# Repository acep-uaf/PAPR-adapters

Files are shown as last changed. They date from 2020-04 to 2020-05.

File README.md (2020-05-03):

# PAPR-adapters

Positive Air Pressure Respirator (PAPR) devices pull air through a filter and push it into a mask over the user's head.  This produces much better protection against droplets than N95 masks or face shields.

A full PAPR system consists of multiple parts:
 * PAPR unit: battery, controller & sensors, air filter, and hose
 * PAPR hose: hose with an end port to connect to a hood
 * PAPR hoods with a hood port

PAPR systems are built to work with a set of components from a specific vendor model and is enforced through physical connector incompatibility between components like hood and hose. Different manufactures hoods and PAPRs units will not work together and even the same manufacture and different models are sometimes incompatible.

The PAPR-adapter project's goal is to provide adapters between different PAPR components to allow them to work together. This allows groups with multiple PAPR units and older/alternative PAPR hoods in their inventory the option of using hoods from one vendor on another vendor's PAPR. This is not typically allowed or considered best practice however in the context of COVID-19 the increased access to limited supply of in-hand PPE is more important.

> USE AT YOUR OWN RISK - THIS IS A STOP-GAP SOLUTION

The PAPR adapter project has helped solve the following adaption problems:

- **Bullard Mask to 3M Hose**:
  2008 era Bullard Hoods to 3M Versaflo PAPR hose

- **Bullard Hose replacement**: 
  Hose connector replacement for older Bullard PAPR units due to breakage of the connector.

- **3M Older BE Hood to Newer 3M Versaflo Hose**: 
  Adapt older BE-10 or BE-12 snap-in hood to newer BT-20, BT-30, or BT-40 type clip-on hose.

- **3M Hood port** - _coming soon_
- **Bullard hood port** - _coming soon_

# Bullard Mask to 3M Hose
This adapts the round 3M PAPR hose to the bayonet-style socket on the Bullard mask/hood.  It allows Bullard Masks to be used with 3M PAPR units.

Mask side: Bullard PAPR hood - port adapter style like Bullard PA30 units.

Hose side: 3M Versaflo PAPR hose
  3M part numbers: BT-20, BT-30, or BT-40 like used in 3M Versaflo TR-6710N.

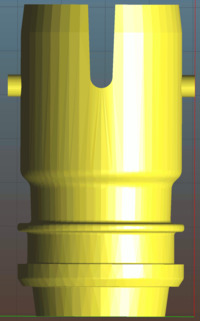
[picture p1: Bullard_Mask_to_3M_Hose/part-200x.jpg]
Top: bayonet-style Bullard mask connector. Bottom: 3M hose connector.


# Bullard Hose Replacement
This connects the corrugated Bullard PAPR hose to the bayonet-style socket on the Bullard mask/hood.  It's a 3D printable replacement for the factory Bullard PAPR hose end.

Mask side: Bullard PAPR hood

Hose side: Bullard PAPR hose

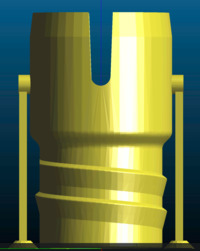
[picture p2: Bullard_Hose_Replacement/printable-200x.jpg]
Top: bayonet-style Bullard mask connector. Bottom: corrugated Bullard hose connector.


# 3M "BE Type" Mask to 3M Clip-On Hose
This plugs into:

Mask side: Older 3M BE-12 or BE-10 snap-in type mask (normally used with unique 3M BE-224 hose).

Hose side: Newer 3M BT-20, BT-30, or BT-40 clip-on type hose.

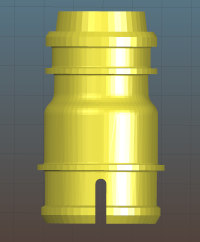
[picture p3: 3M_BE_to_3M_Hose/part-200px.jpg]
Top: 3M clip-on type hose connector. Bottom: 3M snap-in mask connector.


# Sanitization and Safe Use
These parts were designed during the 2020 national COVID-19 crisis as emergency replacement parts to get PAPR units into service.  If you fabricate these parts, they MUST to be checked for material, strength, and dimensional compatibility with the PAPR machines used.  

3D printing can leave crevices that may not be reached by a wipe down, and almost no ordinary plastics can survive an autoclave, so we recommend full immersion sanitization.  NIH 2014 "Infection Prevention and Control of Epidemic- and Pandemic-Prone Acute Respiratory Infections in Health Care" Annex G lists ethanol at 70%, or bleach at 0.05% hypochlorite / 500ppm available chlorine (100 parts cold tap water to 1 part household 5% bleach) for at least 30 minutes.  The bleach solution will need to be rinsed off with water afterwards, or it will leave salt spots.

The UAF Engineering machine shop has tooling to create a strong smooth machined Delrin version of the Bullard Mask to 3M Hose adapter.  Contact uaf-oipc@alaska.edu for pricing and availability.

3M Versaflo and Bullard are trademarks of their respective companies.  These files were developed with support from the University of Alaska Fairbanks Center for Intellectual Property, Commercialization, and Entrepreneurship, including funding from the Office of Naval Research.

# Credits

The PAPR adapters were put together by a team of researchers and engineers at the University of Alaska Fairbanks with funding support from the Office of Naval Research.

* Benjamin Loeffler <bhloeffler@alaska.edu> - Model designer
* Orion Lawlor <oslawlor@alaska.edu> - 3d Printing lead
* Eric Johansen <lejohansen@alaska.edu> - CNC coding for durable/reusable parts
* Dayne Broderson <dbbroderson@alaska.edu> - User interfacing and design requirements
* Greg Shipman <gkshipman@alaska.edu> - 3D printing & consulting

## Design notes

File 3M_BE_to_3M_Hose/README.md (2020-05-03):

# 3M "BE Type" Mask to 3M Clip-On Hose
This plugs into:

3M BE-12 or BE-10 snap-in type mask, normally used with a 3M BE-224 hose.

3M BT-20, BT-30, or BT-40 clip-on type hose.

Top: 3M clip-on type hose connector. Bottom: 3M snap-in mask connector.

The SLDPRT SolidWorks original was designed by Benjamin Loeffler <bhloeffler@alaska.edu>.

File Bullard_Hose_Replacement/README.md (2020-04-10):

# Bullard Hose Replacement
This is a 3D printed replacement for factory Bullard PAPR hose to mask connection.

You use heat shrink tubing to connect the hose to this adapter.

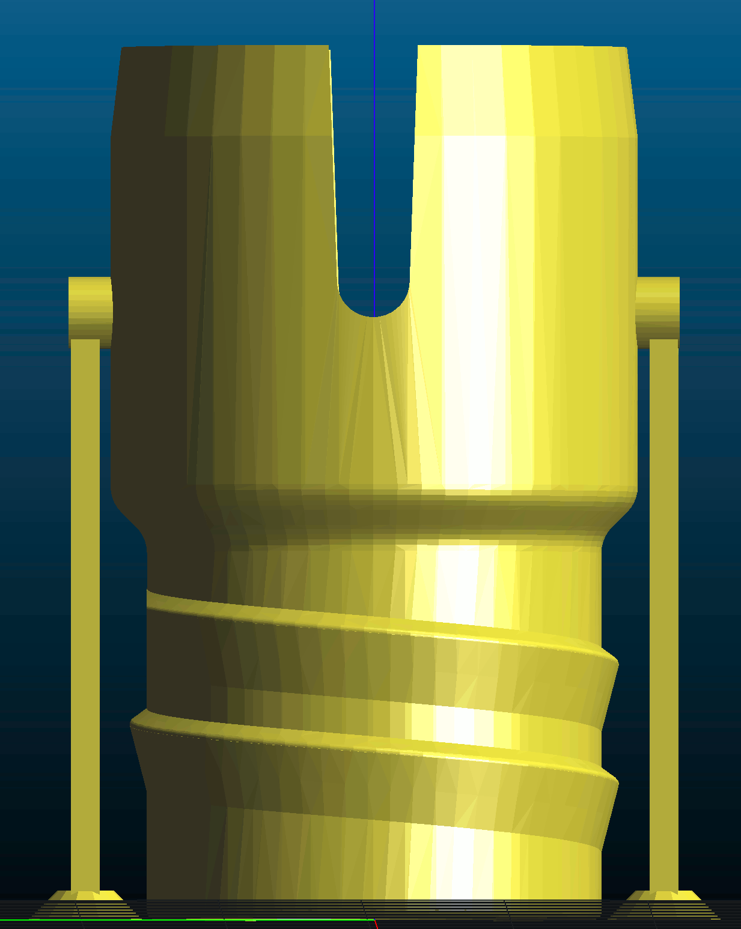
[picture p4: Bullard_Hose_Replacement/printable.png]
Top: bayonet-style Bullard mask connector. Bottom: corrugated Bullard hose connector.


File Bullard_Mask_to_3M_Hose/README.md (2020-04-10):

# Bullard Mask to 3M Hose
This plugs into the round 3M PAPR-side hose, and lets it connect to the bayonet-style Bullard mask/hood.

It allows you to use a Bullard mask/hood with a 3M Versaflow PAPR unit.

Because the round features on the 3M side are rather challenging to 3D print effectively, the "lathe_finished" directory includes extra material that is machined away.

The SLDPRT SolidWorks original was designed by Benjamin Loeffler <bhloeffler@alaska.edu>.  The CNC and 3D printing adaptations were designed by Dr. Orion Lawlor <lawlor@alaska.edu>.

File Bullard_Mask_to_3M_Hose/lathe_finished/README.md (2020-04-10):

# Lathe Finished Version

This version includes extra 3D printed material on the 3M side, 
which is then machined off on a CNC lathe using the gcode in cleanup_operation_lathe.ngc.

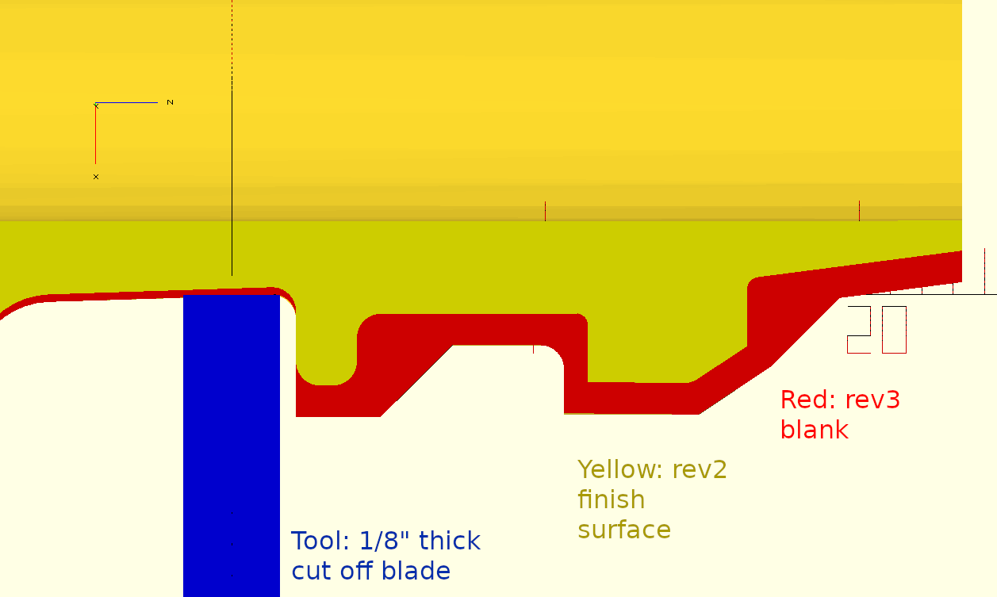
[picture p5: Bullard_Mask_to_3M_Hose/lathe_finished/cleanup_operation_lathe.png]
Gcode for the lathe cleanup operation


The "_upright" version is designed to be 3D printed directly on the print
bed without additional support material--it has two tiny diagonal supports
around the Bullard "ears".

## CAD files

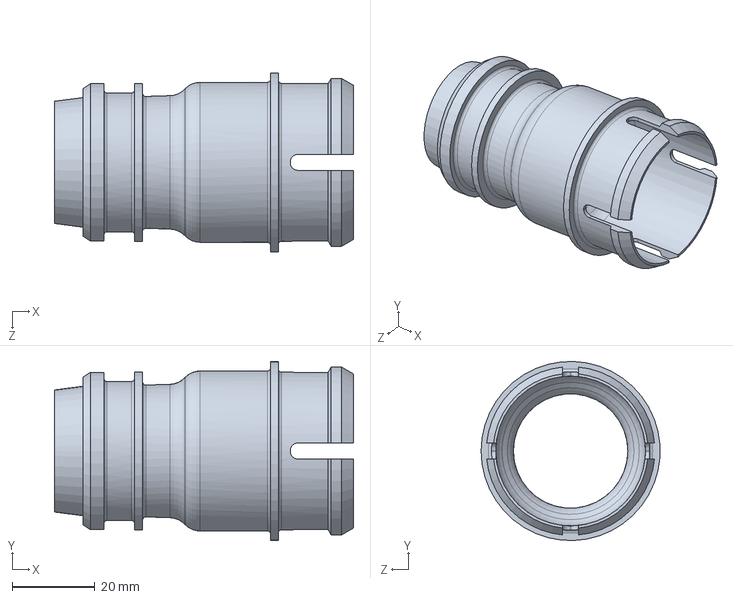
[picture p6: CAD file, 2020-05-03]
3M_BE_to_3M_Hose/BE_3M_adapter_rev2_thin.SLDPRT
72.1 x 43.2 x 43.1 mm

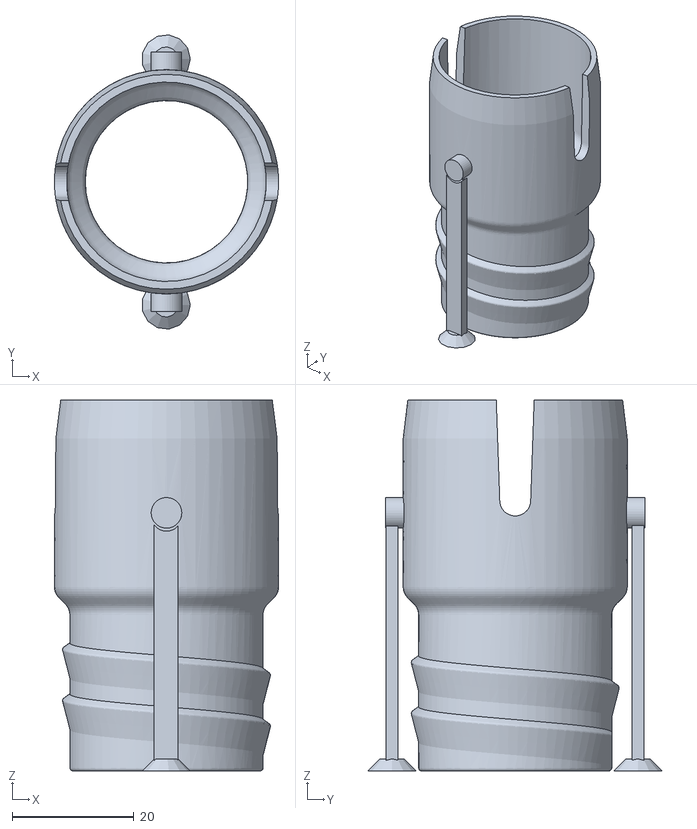
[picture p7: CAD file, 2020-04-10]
Bullard_Hose_Replacement/printable_Bullard_Hose_Replacement_rev2.stl
36.8 x 48.3 x 61.0

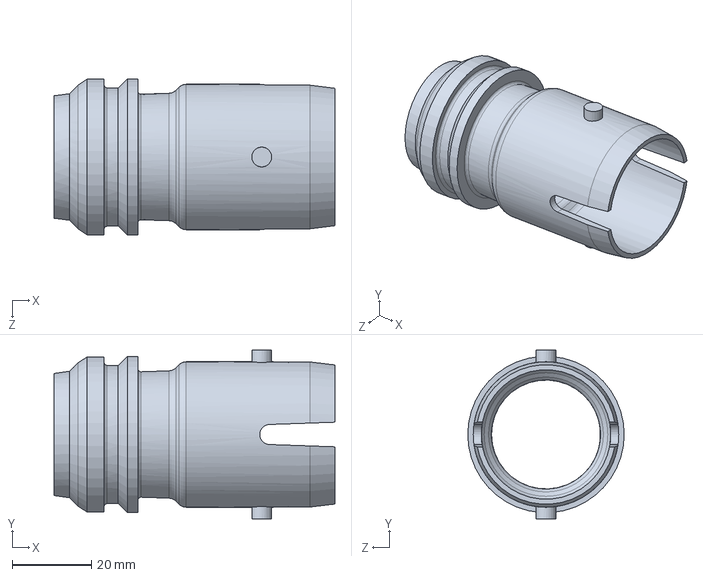
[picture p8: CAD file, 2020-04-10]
Bullard_Mask_to_3M_Hose/lathe_finished/Bullard_Mask_to_3M_Hose_rev3_ForLathe.SLDPRT
71.1 x 42.7 x 39.6 mm

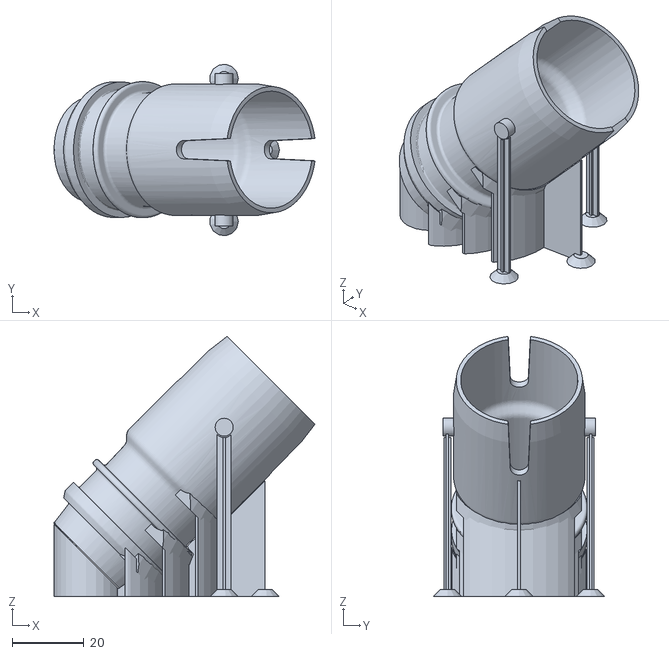
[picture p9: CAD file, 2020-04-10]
Bullard_Mask_to_3M_Hose/printable_Bullard_Mask_to_3M_Hose.stl
73.0 x 47.9 x 72.8

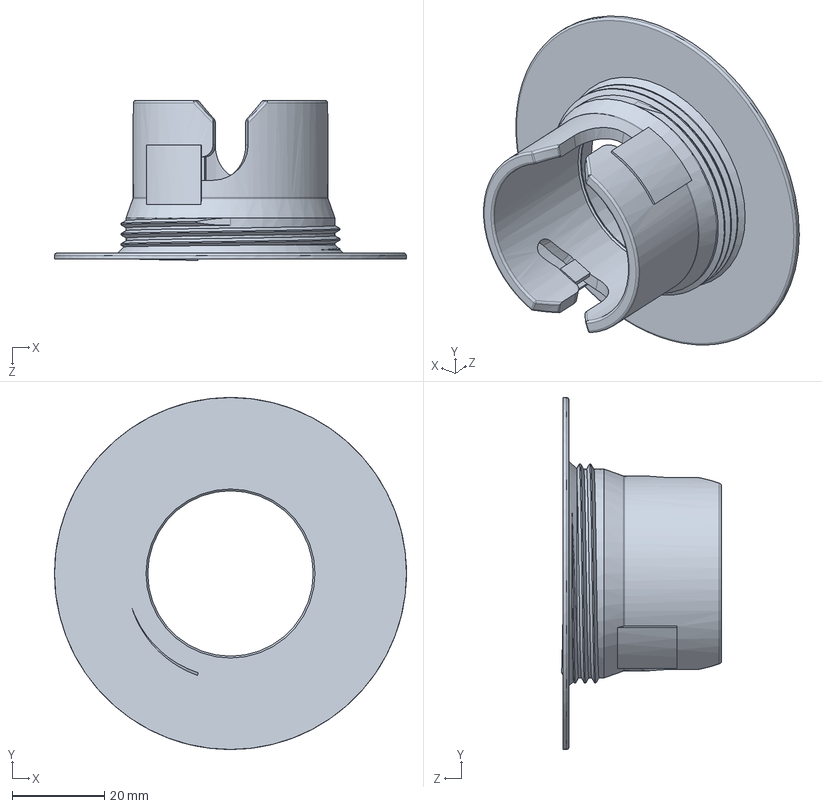
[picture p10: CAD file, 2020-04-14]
Bullard_Socket/Bullard_Socket_threaded_rev2.SLDPRT
76.2 x 76.2 x 34.6 mm

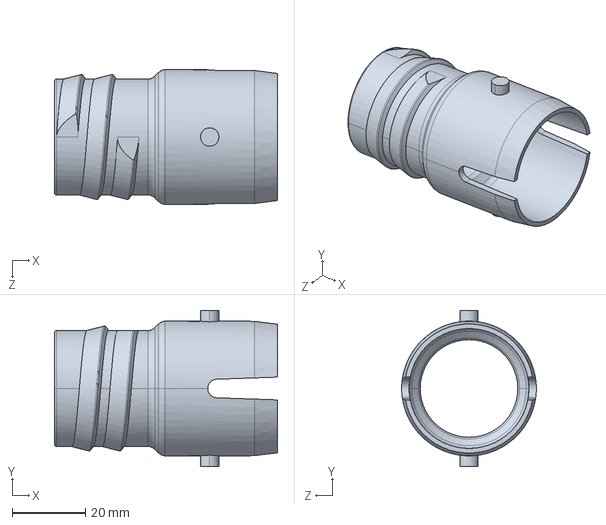
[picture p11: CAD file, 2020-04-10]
Bullard_Hose_Replacement/Bullard_Hose_Replacement_rev2.STEP
61.0 x 42.7 x 36.8 mm

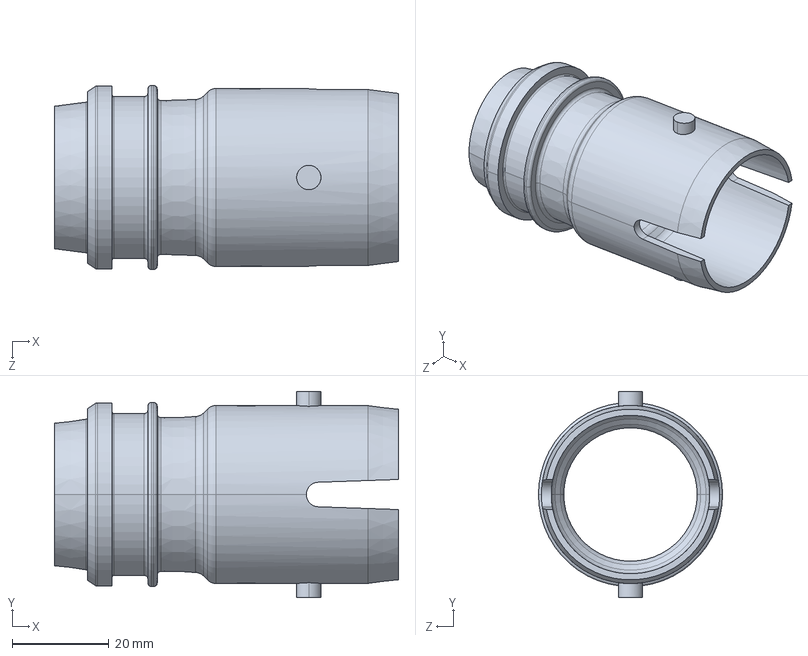
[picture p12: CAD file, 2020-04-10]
Bullard_Mask_to_3M_Hose/Bullard_Mask_to_3M_Hose.STEP
71.1 x 42.7 x 38.1 mm

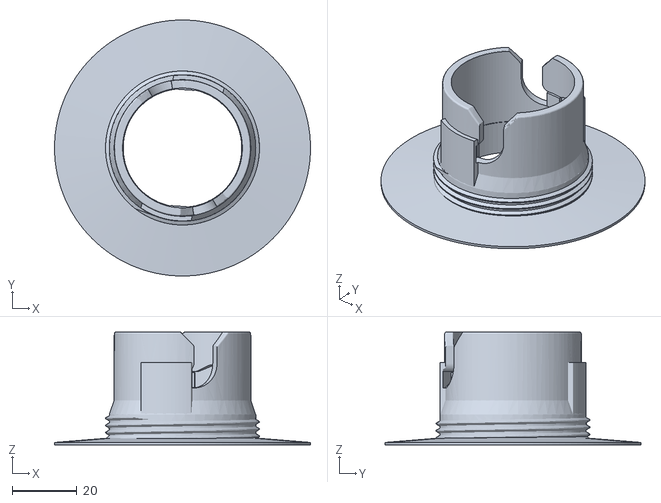
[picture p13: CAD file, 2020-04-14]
Bullard_Socket/Bullard_Socket_v3.stl
79.0 x 79.0 x 34.9

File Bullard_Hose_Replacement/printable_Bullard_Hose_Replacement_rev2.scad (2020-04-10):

/*
  Support material for Bullard Hose Replacement, standing upright.
  
  OpenSCAD code by Dr. Orion Lawlor, 2020-04-03
*/

spacing=0.5;

module main_part()
{
	translate([18.5,-21.3])
	rotate([0,-90,0])
		import("Bullard_Hose_Replacement_rev2.stl");
}

module support_material() 
{
	height=42;
	for (side=[-1,+1]) scale([1,side,1])
		translate([0,20.2,0])
		union() {
			translate([0,0,height/2])
				cube([4,2,height],center=true);
			
			cylinder(d1=8,d2=4,h=2);
		}
}

main_part();
difference() {
	support_material();
	
	// Leave space around the main part
	translate([0,0,-spacing])
		main_part();
}

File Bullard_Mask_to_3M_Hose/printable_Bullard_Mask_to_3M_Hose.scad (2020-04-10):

/*
  Support material for Bullard_Mask_to_3M_Hose,
  tilted over sideways, and supported.
  
  OpenSCAD by Dr. Orion Lawlor <lawlor@alaska.edu>
*/

spacing=0.4; // distance between support material and part
height=53; // original upright distance to pegs
tiltover=45; // angle of tilt (0==upright)
support_height=47.5; // post-rotate distance to pegs
support_width=0.7;

// Comes out upright and centered
module main_part()
{
	translate([18.8,-21.25])
	rotate([0,-90,0])
		import("Bullard_Mask_to_3M_Hose.stl",convexity=6);
}

// Main part, with inside filled in solid (to cut support material)
module main_part_solid() {
	main_part();
	cylinder(d=28,h=45);
	translate([0,0,43]) cylinder(d=34,h=30);
}

// Tilt part over to printable orientation
module part_tilt() {
	translate([0,0,+support_height])
	rotate([0,tiltover,0])
	translate([0,0,-height])
		children();
}

// Tapered stick down
module stickdown() {
	cylinder(d1=8,d2=4,h=2);
}


// Support-type rings are defined relative to un-tilted part
module support_ring(z,OD,wall,topclip,flare=1)
{
	color([1,0,0]) union() {
		difference() {
			// Project down to support each ridgeline
			linear_extrude(height=30,convexity=4)
			projection(cut=false)
			part_tilt()
			translate([0,0,z])
			{
				linear_extrude(height=1)
				difference() {
					circle(d=OD);
					circle(d=OD-2*wall);
					translate([topclip-100,0,0]) square([200,200],center=true);
				}
			}
		
			// Trim those supports along (tilted) z
			part_tilt()
			translate([0,0,z+1+100])
				cube([200,200,200],center=true);
		}
		
		if (flare) { // flare out object contact surface
			part_tilt() {
				intersection() {
				translate([0,0,z-1.5]) {
					cylinder(d1=OD+3,d2=OD-1,h=4.5);
					/*
					scale([1,1,-1])
					cylinder(d1=OD+5,d2=OD-2,h=1);
					*/
				}
				translate([OD/2,0,z])
					cube([30,35,100],center=true);
				}
			}
		}
	}
}

// Support towers over pegs
module support_towers()
{
	for (side=[-1,+1]) scale([1,side,1])
		translate([-0.5,20.0,0])
		union() {
			translate([0,0,support_height/2]) union() {
				cube([4,support_width,support_height],center=true);
				cube([support_width,2,support_height],center=true);
			}
			
			stickdown();
		}
}

module all_support_material() {
	difference() {
		union() {
			spine_length=38;
			spine_width=support_width;
			translate([-27,0,0]) 
			{
				difference() {
					translate([0,-spine_width/2,0])
					cube([spine_length,spine_width,50]);
					translate([0,0,0.5]) rotate([0,-90+tiltover+2,0]) 
						translate([0,0,100]) cube([200,200,200],center=true);
				}
				
				// Support the part base
				translate([-1.5,0,2]) cube([5,20,4],center=true);
				
				// Keep tip from coming up
				translate([spine_length,0,0])
					stickdown();
			}
			
			ring_width=support_width*0.5;
			support_ring(-0.8,28.2,ring_width,-50,0);
			support_ring(8.2,39,ring_width,5);
			support_ring(18.0,39,ring_width,10);
			support_ring(31,37,ring_width,10);
			
			support_towers();
		}
		
		// Leave space around the main part
		for (shift=[[0,0,-spacing],[0,+spacing,0],[0,-spacing,0],[spacing,0,0],[0,0,+spacing]])
			translate(shift)
				part_tilt() main_part_solid();
	}
}

intersection() {
	union() {
		part_tilt() main_part();

		all_support_material();
	}
	
	// Trim bottom flat
	color([0,1,0])
	translate([0,0,100]) cube([200,200,200],center=true);
}

if (0) difference() {
	main_part_solid();
	cube([100,100,100]);
}

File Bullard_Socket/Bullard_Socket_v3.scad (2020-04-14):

/*
 Female socket for Bullard Hoods.
*/

$fs=0.1;
$fa=3;
inch=25.4; // file units are mm

ID=1.455*inch;// male side fits in here
OD=41.0; // OD of main outside
OD_track=43.5; // OD along bottom of peg track
TD=OD+2*2;

bottom_shorten=4.5;
new_bottom=TD+17*2;

module fit_test_male() {
	translate([0,0,72.7])
	scale([1,1,-1])
		import("../PAPR_adapter/Old_Mask_to_New_Hose_rev3_upright.stl",convexity=4);
}

module connector() {
	rotate([0,0,20])
	translate([-76.2/2,76.2/2,39.37])
	rotate([180,0,0])
	import("Bullard Hood Connector_threaded.STL",convexity=8);
}

module thread_split(offset=0) {
	translate([0,0,-100+14.1+offset])
		cube([200,200,200],center=true);
}

module reinforced_connector() {
	// Outer lug supports (permanent)
	intersection() {
		rotate([0,0,-14])
		cube([16,100,100],center=true);
		difference() {
			translate([0,0,10])
				cylinder(d=TD,h=20);
			
			// Thru hole in middle
			translate([0,0,-1])
			cylinder(d=OD,h=32);
			
			// Extra-deep tracks
			difference() {
				translate([0,0,20])
				cylinder(d=OD_track,h=12);
			
				intersection() {
					s=OD_track/OD;
					translate([0,0,0.01])
					scale([s,s,1])
						connector();
					
					translate([0,0,25])
					cube([30,100,10],center=true);
				}
			}

		}
	}
	
	// Inner lug start support (temporary, removed after printing)
	rotate([0,0,-4]) {
		for (side=[-1,+1]) scale([1,side,1])
			translate([0,ID/2,24.6])
				cube([5,1,4.6],center=true);
	}
	
	
	difference() {
		union() {
			scale([-1,1,1]) 
			intersection() {
				connector();
				thread_split();
			}
			difference() {
				connector();
				thread_split(-0.01);
			}
		}
		
		// Clearance inside for male plug
		translate([0,0,15])
			cylinder(d=ID,h=100);
	}
}

module shortened_connector() {
	difference() {
		translate([0,0,-bottom_shorten])
			reinforced_connector();

		// Cut off bottom flush
		translate([0,0,-100+0.001])
			cube([200,200,200],center=true);
		
	}
	
	difference() {
		union() {
			cylinder(d=new_bottom,h=0.7);
			translate([0,0,0.8-0.01])
				cylinder(d1=new_bottom,d2=42,h=1.5);
			
			translate([0,0,0.1])
				cylinder(d1=OD+2*5,d2=OD,h=5);
		}
		cylinder(d=OD,h=100,center=true);
	}
}

difference() {
	union() {
		shortened_connector();
		// fit_test_male();
	}
	// cube([100,100,100]); // cutaway
}

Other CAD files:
Bullard_Mask_to_3M_Hose/lathe_finished/printable_Bullard_Mask_to_3M_Hose_rev3.stl
Bullard_Mask_to_3M_Hose/lathe_finished/printable_Bullard_Mask_to_3M_Hose_rev3.scad
3M_BE_to_3M_Hose/BE_3M_adapter_rev2_thin.stl
Bullard_Hose_Replacement/Bullard_Hose_Replacement_rev2.SLDDRW
Bullard_Hose_Replacement/Bullard_Hose_Replacement_rev2.SLDPRT
Bullard_Hose_Replacement/Bullard_Hose_Replacement_rev2.stl
Bullard_Mask_to_3M_Hose/Bullard_Mask_to_3M_Hose.SLDDRW
Bullard_Mask_to_3M_Hose/Bullard_Mask_to_3M_Hose.SLDPRT
Bullard_Mask_to_3M_Hose/Bullard_Mask_to_3M_Hose.stl
Bullard_Mask_to_3M_Hose/lathe_finished/Bullard_Mask_to_3M_Hose_rev3_ForLathe.stl
Bullard_Mask_to_3M_Hose/lathe_finished/Bullard_Mask_to_3M_Hose_rev3_ForLathe.x_t
Bullard_Socket/Bullard_Socket_threaded_rev2.stl

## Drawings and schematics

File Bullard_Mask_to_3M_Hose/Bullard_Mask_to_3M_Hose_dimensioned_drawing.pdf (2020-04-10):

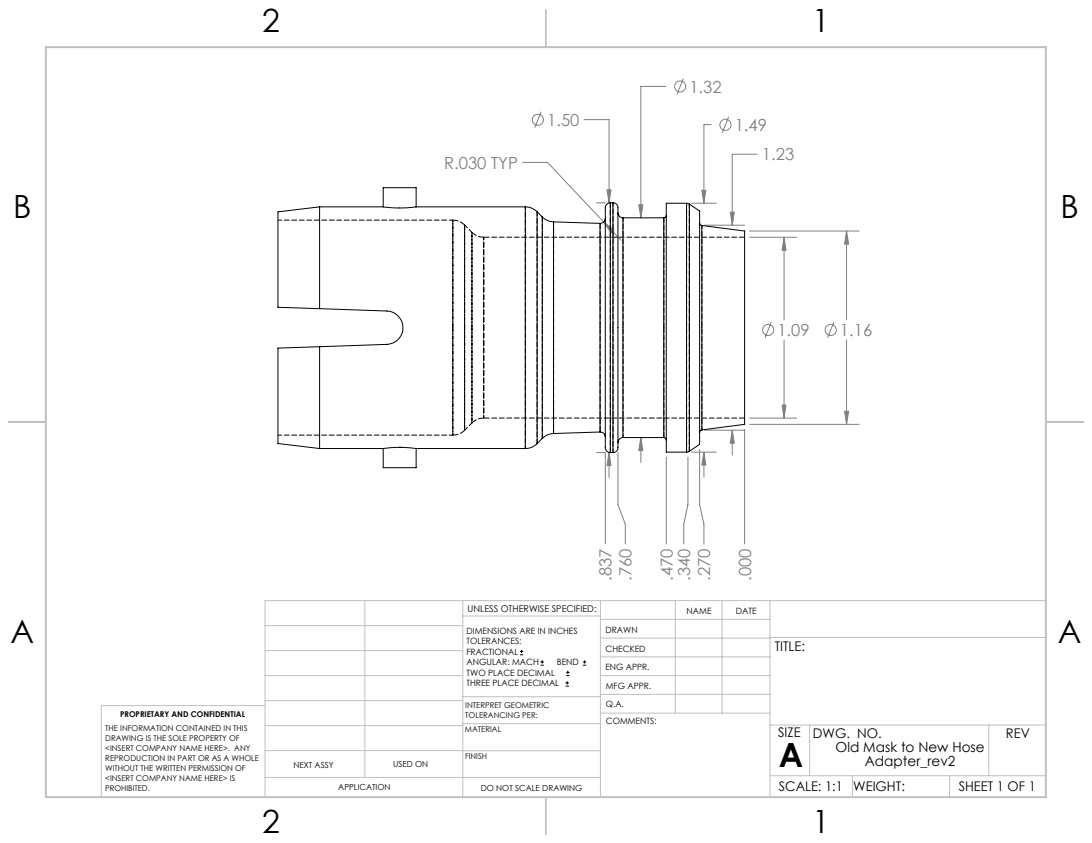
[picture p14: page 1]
R.030 TYP

UNLESS OTHERWISE SPECIFIED: | | NAME | DATE
DIMENSIONS ARE IN INCHES TOLERANCES: FRACTIONAL ANGULAR: MACH BEND TWO PLACE DECIMAL THREE PLACE DECIMAL | DRAWN

CHECKED | | | TITLE:

ENG APPR.
MFG APPR.

INTERPRET GEOMETRIC TOLERANCING PER: | Q.A.
MATERIAL | | SIZE A | DWG. NO. Old Mask to New Hose Adapter_rev2 | REV

PROPRIETARY AND CONFIDENTIAL
THE INFORMATION CONTAINED IN THIS
DRAWING IS THE SOLE PROPERTY OF
<INSERT COMPANY NAME HERE>. ANY
REPRODUCTION IN PART OR AS A WHOLE
WITHOUT THE WRITTEN PERMISSION OF
<INSERT COMPANY NAME HERE> IS
PROHIBITED.

NEXT ASSY | USED ON | FINISH

APPLICATION | DO NOT SCALE DRAWING | | SCALE: 1:1 | WEIGHT: | SHEET 1 OF 1

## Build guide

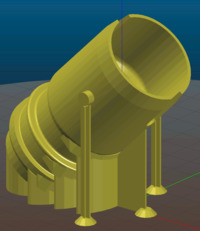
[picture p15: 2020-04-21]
Bullard_Mask_to_3M_Hose/printable-200x.jpg

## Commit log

2020-04-10 Added binaries from "Medical CAD" folder.
    [Bullard_Hose_Replacement_rev2.SLDDRW, Bullard_Hose_Replacement_rev2.SLDPRT, Bullard_Hose_Replacement_rev2.STEP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]
2020-04-10 Rename "upright" versions as "printable", for consistency with the other names.
    [printable_Bullard_Mask_to_3M_Hose_rev3.scad, printable_Bullard_Mask_to_3M_Hose_rev3.stl]
2020-04-14 Added Bullard female socket, to go on a mask/hood.
    [Bullard_Mask_threaded_rev2.SLDPRT, Bullard_Mask_threaded_rev2.stl, Bullard_Mask_v3.scad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]
2020-04-15 Renamed "Bullard Mask" as "Bullard Socket", to clarify the gender.
    [Bullard_Socket_threaded_rev2.SLDPRT, Bullard_Socket_threaded_rev2.stl, Bullard_Socket_v3.scad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]
2020-05-03 Added 3M BE type to 3M versaflow type hose (as requested by the fire department).
    [BE_3M_adapter_rev2_thin.SLDPRT, BE_3M_adapter_rev2_thin.stl]
